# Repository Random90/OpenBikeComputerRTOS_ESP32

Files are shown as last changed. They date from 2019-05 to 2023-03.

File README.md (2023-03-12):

# Open Bike Computer RTOS

## Summary
This repo is an open source bike computer based on freeRTOS on ~~ESP8266~~ ESP32. (ESP32 is much newer hardware, no reason to stick with esp8266 right now)
This is an attempt of learning C and freeRTOS env. I've first made bike computer using arduino nano, so this might be refered as version 2. I've also tackled a little of 3d design in blender to create a case for this bike computer.

Creating community around this project for all programmers riding their bikes would be awesome :)

## Features
### Core:
- current speed, distance, time
- average, max speed, total distance

### Memory:
- average/max speed and total distance are stored on the device (not synchronized for now, only local)

### Display:
- shows main and detailed ride data
- bottom half of the screen changes automaticly (8s 'big' distance, 3s details)

### Synchronization using WiFi:
- synchronize ride data with OBC Server (see https://github.com/Random90/OBC_Server)
- wifi settings are hardcoded at compile-time
- data is sent the the obc_server on ride stop as a new ride after 30 seconds of inactivity (configurable at compile-time)
- ride is restarted automaticly after ride synchonization succeded
- sntp time synchronization - sets timestamp for your rides 
### Current supported hardware:
- ESP32
- Reed Switch
- pcd8544 Nokia 5110 LCD

### 3D Printable case
See /3dcase folder for files. Print both "obc_case_bottom" and obc_case_top" .stl files.

### Additional funcionality TODOS and ideas:
- better sleep mode for battery performance
- local ride storage for later sync (on new ride started by button press) (spiffs)
- full ride logs with file rotation
- wifi access point setup, multiple WIFI access point settings
- timezone settings for time display
- modularization of components (start with screen selection at compile-time)
- different hardware support e.g different type of screens like OLED, E-ink, color LCD
- buttons
- automatic screen brightness
- live, reed impulse online sync (share your ride data realtime)
- sync with Strava API, Wifi geolocation.
- Even later in future: GPS module, GPRS module for live tracking. 

## Hardware

## Prototype version

Pritable case for version with no soldering required, everything connected with Dupont cables. Uses ESP devkit with pins, nokia 5110 screen with pins soldered. Powered up by micro usb cable.

prorotype

### Required components 
- ESP_WROOM_32 DEVKIT V1 
- Nokia 5110 LCD HXE
- Reed switch

### Default wiring
OBC uses VSPI (can be HSPI, but I use it for debug) to connect to LCD:
| ESP32 | LCD |
--- | --- |
| D4 | RST |
| D5 | CE |
| D25 | DC |
| D19 | DIN |
| D18 | CLK |
| 3V3/5V | VIN |
| RX2/G16 | BL |
| GND | GND |

ReedSwitch -> ESP D21 PIN -> GND

JTAG CJMCU-2232HL (note to myself)

| ESP32 | JTAG |
--- | --- |
| D13 | AD0 |
| D12 | AD1 |
| D15 | AD2 |
| D14 | AD3 |
| GND | GND |
## Micro fork version with battery
Work in progress!
## Standard version
Soon
## Standard version with battery
Soon+

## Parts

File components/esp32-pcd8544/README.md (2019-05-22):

# ESP32-PCD8544

A dedicated driver library implementation of PCD8544 graphic controller for
[Espressif IoT Development Framework (ESP-IDF)](https://github.com/espressif/esp-idf).

(PCD8544 is a.k.a. [Nokia 5110 LCD module](https://www.google.co.jp/search?q=nokia5110+lcd&tbm=isch)).

Documentation and API reference is available at readthedocs.org.


http://esp32-pcd8544.readthedocs.io/en/latest/

Application examples are in separeted repository: https://github.com/yanbe/esp32-pcd8544-examples

## Key Features

- All functionalities in the PCD8544 datasheet are implemented
- Enforce native pin assignemnt for fast and low latency IO\_MUX direct IO.
- Manual Pin assignment is availble via API  ( no #define PIN\_NUM\_XX in header files)
- Asyncronous DMA-transfer mode is supported on HSPI / VSPI host
- Efficient draw lines / formatted text / bitmap APIs
- Good sample codes / examples (TBD)

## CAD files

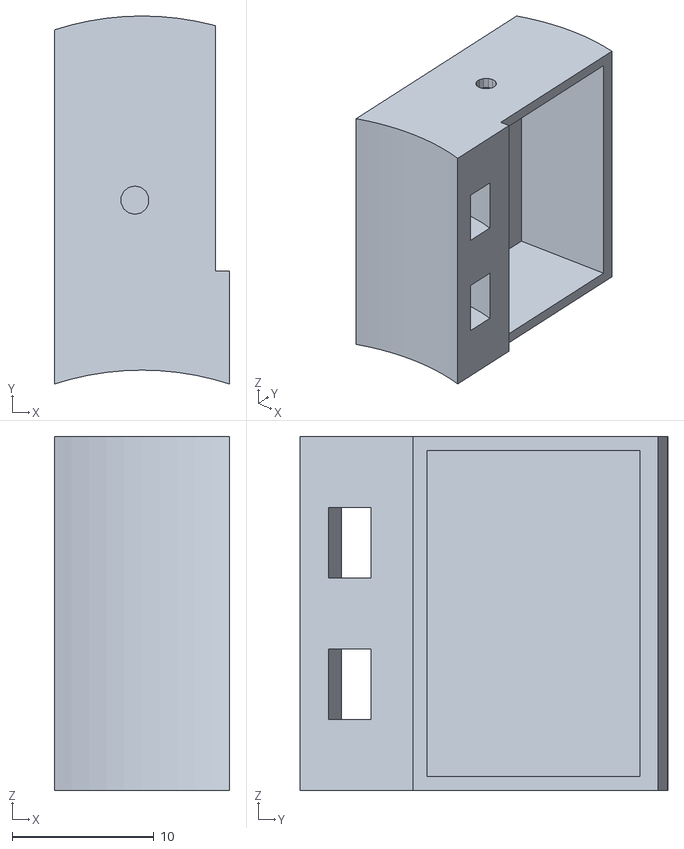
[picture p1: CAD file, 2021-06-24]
3dcase/reedSwitchHolder-main.stl
12.4 x 26.0 x 25.0

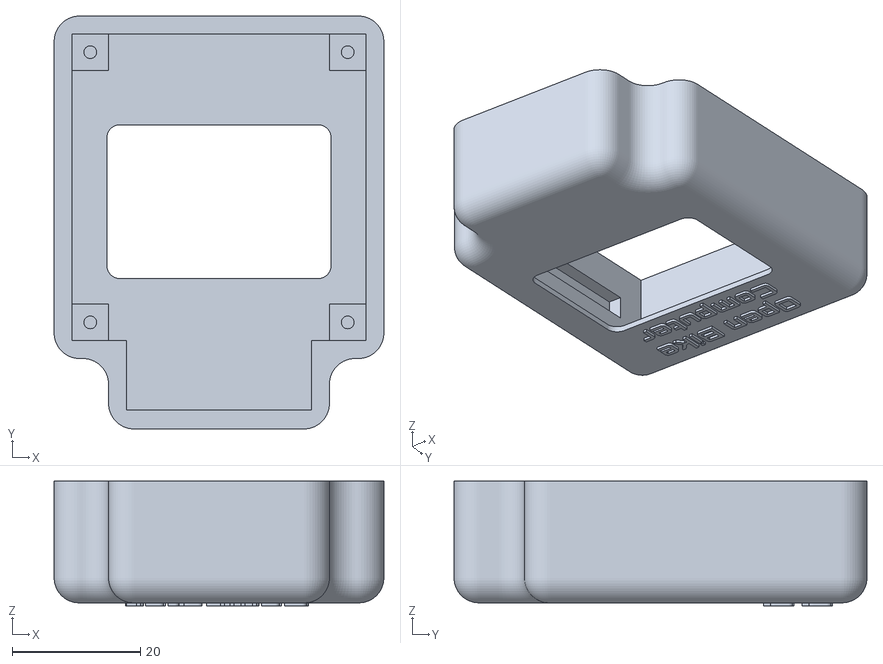
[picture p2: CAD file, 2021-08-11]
3dcase/obc_case_top.stl
51.5 x 64.5 x 19.5

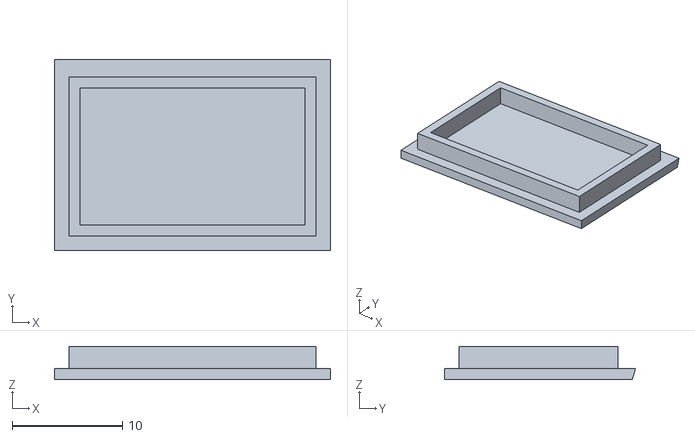
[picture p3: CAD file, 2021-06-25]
3dcase/reedSwitchHolder-cap.stl
25.0 x 17.3 x 3.00

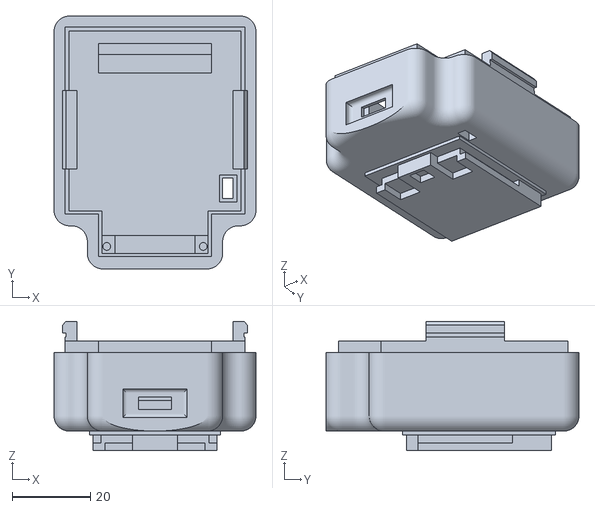
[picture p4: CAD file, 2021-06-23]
3dcase/obc_case_bottom.stl
51.5 x 64.5 x 33.0

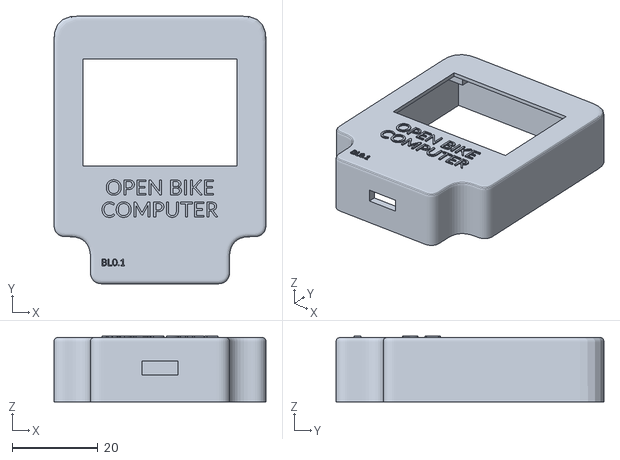
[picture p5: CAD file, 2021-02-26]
3dcase/obc_case_top_text.obj
49.5 x 62.5 x 15.3

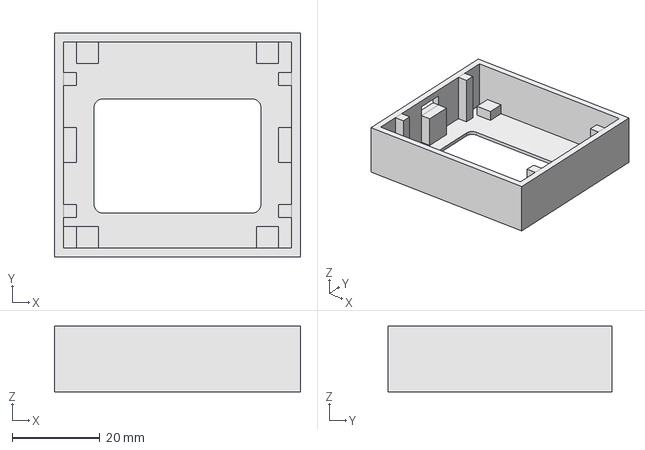
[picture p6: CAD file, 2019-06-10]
3dcase/v1.2_front.FCStd
56.0 x 51.0 x 15.0 mm

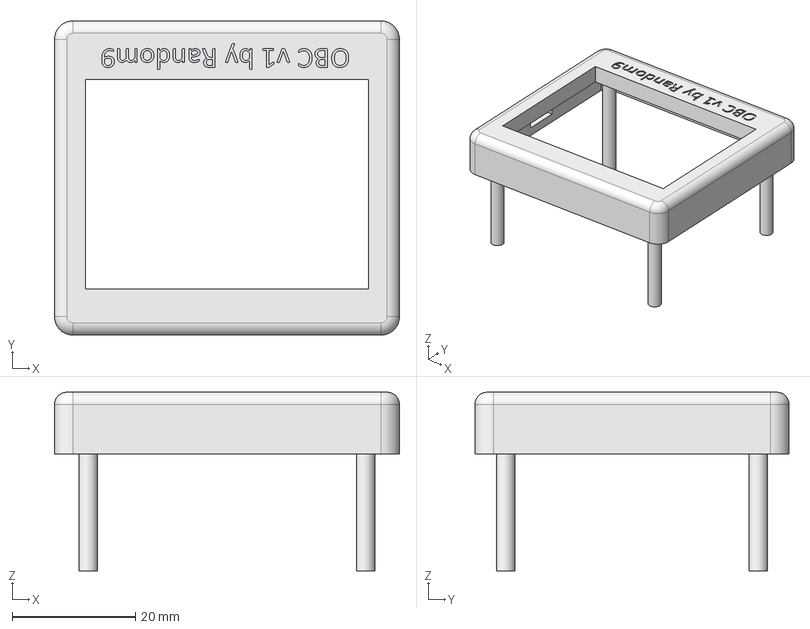
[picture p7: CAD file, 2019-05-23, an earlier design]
3dcase/v1_front.FCStd
56.0 x 51.0 x 29.0 mm

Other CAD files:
3dcase/v1.1_front.FCStd
3dcase/source/obc_case_bottom.blend
3dcase/source/obc_case_bottom_m.blend
3dcase/source/obc_case_mount_only.blend
3dcase/source/obc_case_top.blend
3dcase/source/reedSwitchHolder.blend
3dcase/v1.1_front.obj
3dcase/v1.2_front.obj
3dcase/v1_front.obj

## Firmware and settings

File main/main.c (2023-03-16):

#ifndef NO_SCREEN
#include "Tasks/screen_pcd8544/screen_pcd8544.h"
#include "driver/spi_common.h"
#endif

#include <stdio.h>
#include <stdlib.h>

#include "Tasks/core/calcRideParamsOnISR.task.h"
#include "Tasks/core/rideStatusWatchdog.task.h"
#include "Tasks/storage/spiffs_main.h"
#include "Tasks/sync/obc_rest.task.h"
#include "Tasks/sync/sntp.task.h"
#include "driver/gpio.h"
#include "esp_event_base.h"
#include "esp_log.h"
#include "esp_system.h"
#include "freertos/FreeRTOS.h"
#include "freertos/queue.h"
#include "freertos/task.h"
#include "nvs_flash.h"
#include "obc.h"
#include "sdkconfig.h"
#include "settings.h"
#include "utils/math.h"

#define TAG "OBC_MAIN"

// obc event loop
ESP_EVENT_DEFINE_BASE(OBC_EVENTS);
esp_event_loop_handle_t obc_events_loop;
esp_event_loop_args_t obc_events_loop_args = {
    .queue_size = 5,
    .task_name = "obc_events_loop_task",
    .task_priority = 7,
    .task_stack_size = 2048,
    .task_core_id = tskNO_AFFINITY};

// declare global queues
QueueHandle_t reed_evt_queue = NULL;

// declare OBC global ride params
ride_params_t rideParams = {
    .moving = false,
    .rotations = 0,
    .prevRotationTickCount = 0,
    .totalRideTimeMs = 0,
    .speed = 0.0,
    .avgSpeed = 0.0,
    .distance = 0.0,
    .maxSpeed = 0.0,
    .globalMaxSpeed = 0.0,
    .totalDistance = 0.0,
    .startedTimestamp = 0};

// IRAM_ATTR - function with this will be moved to RAM in order to execute faster than default from flash
static void IRAM_ATTR vReedISR(void* arg) {
    BaseType_t xHigherPriorityTaskWoken = pdFALSE;
    TickType_t xLastReedTickCount = xTaskGetTickCountFromISR();

    xQueueSendFromISR(reed_evt_queue, &xLastReedTickCount, &xHigherPriorityTaskWoken);
    if (xHigherPriorityTaskWoken) {
        portYIELD_FROM_ISR();
    }
}

void vInitTasks() {
    xTaskCreate(&vCalcRideParamsOnISRTask, "vCalcRideParamsOnISRTask", 2048, NULL, 6, NULL);
    xTaskCreate(&vRideStatusWatchdogTask, "vRideStatusIntervalCheckTask", 2048, NULL, 3, NULL);
    xTaskCreate(&vSntpSyncTask, "vSntpSyncTask", 4096, NULL, 3, NULL);
    vRegisterServerSyncTask();
}

void vAttachInterrupts() {
    ESP_LOGI(TAG, "Attaching reed switch interrupt");
    // create queue for the reed interrupt
    reed_evt_queue = xQueueCreate(10, sizeof(uint32_t));

    // configure reed switch gpio
    gpio_config_t io_conf;
    io_conf.mode = GPIO_MODE_INPUT;
    // bit mask of the pins that you want to set,e.g.GPIO18/19
    io_conf.pin_bit_mask = 1ULL << REED_IO_NUM;
    io_conf.pull_up_en = 1;
    io_conf.pull_down_en = 0;
    io_conf.intr_type = GPIO_INTR_NEGEDGE;
    // configure GPIO with the given settings
    gpio_config(&io_conf);
    // gpio_set_intr_type(REED_IO_NUM, GPIO_INTR_NEGEDGE);
    gpio_install_isr_service(ESP_INTR_FLAG_DEFAULT);
    gpio_isr_handler_add(REED_IO_NUM, vReedISR, NULL);
}

void vInitNVS() {
    esp_err_t ret = nvs_flash_init();
    if (ret == ESP_ERR_NVS_NO_FREE_PAGES || ret == ESP_ERR_NVS_NEW_VERSION_FOUND) {
        ESP_ERROR_CHECK(nvs_flash_erase());
        ret = nvs_flash_init();
    }
    ESP_ERROR_CHECK(ret);
}

void testHandler(void* handler_args, esp_event_base_t base, int32_t id, void* event_data) {
    ESP_LOGI(TAG, "handling %s %" PRIu32, base, id);
}

void app_main() {
    ESP_LOGI(TAG, "Initializing");
    ESP_ERROR_CHECK(esp_event_loop_create_default());
    // event loop created with task with priority 7
    ESP_ERROR_CHECK(esp_event_loop_create(&obc_events_loop_args, &obc_events_loop));

    vInitNVS();
    vInitSpiffs();
    vAttachInterrupts();
    vInitTasks();
#ifndef NO_SCREEN
    vInitPcd8544Screen();
#endif

    ESP_ERROR_CHECK(esp_event_handler_register_with(obc_events_loop, OBC_EVENTS, ESP_EVENT_ANY_ID, testHandler, obc_events_loop));
    ESP_LOGI(TAG, "Startup complete");
}

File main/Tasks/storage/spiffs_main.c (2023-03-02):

#include "spiffs_main.h"

#include "esp_err.h"
#include "esp_log.h"
#include "esp_spiffs.h"
#include "obc.h"

#define TAG "SPIFFS_MAIN"

//@TODO saving ride data

TaskHandle_t spiffsSyncOnStopTaskHandle = NULL;

// values read from files
float maxSpeedFileBuff = 0.00;
float totalDistanceFileBuff = 0.00;

void vReadMaxSpeed() {
    FILE *fmaxSpeed = fopen("/spiffs/max_speed", "rb");
    if (fmaxSpeed == NULL) {
        ESP_LOGE(TAG, "Failed to open file max_speed");
        return;
    } else {
        fread(&maxSpeedFileBuff, 1, sizeof(maxSpeedFileBuff), fmaxSpeed);
        fclose(fmaxSpeed);
        ESP_LOGI(TAG, "max speed from file %f", maxSpeedFileBuff);
    }
}

void static vReadTotalDistance() {
    FILE *ftotalDistance = fopen("/spiffs/total_distance", "rb");
    if (ftotalDistance == NULL) {
        ESP_LOGE(TAG, "Failed to open file total_distance");
        return;
    } else {
        fread(&totalDistanceFileBuff, 1, sizeof(totalDistanceFileBuff), ftotalDistance);
        fclose(ftotalDistance);
        ESP_LOGI(TAG, "total distance from file %f", totalDistanceFileBuff);
    }
}

static void vSaveMaxSpeed(float speed) {
    ESP_LOGI(TAG, "[SAVING] maxSpeed: %f", speed);
    FILE *fmaxSpeed = fopen("/spiffs/max_speed", "wb");
    if (fmaxSpeed == NULL) {
        ESP_LOGE(TAG, "Failed to open file max_speed for update");
        return;
    } else {
        fwrite(&speed, 1, sizeof(speed), fmaxSpeed);
        fclose(fmaxSpeed);
        maxSpeedFileBuff = speed;
    }
}

static void vSaveTotalDistance() {
    if (rideParams.totalDistance > totalDistanceFileBuff) {
        ESP_LOGI(TAG, "[SAVING] totalDistance: %f", rideParams.totalDistance);
        FILE *fTotalDistance = fopen("/spiffs/total_distance", "wb");
        if (fTotalDistance == NULL) {
            ESP_LOGE(TAG, "Failed to open file total_distance for update");
            return;
        } else {
            fwrite(&rideParams.totalDistance, 1, sizeof(rideParams.totalDistance), fTotalDistance);
            fclose(fTotalDistance);
            totalDistanceFileBuff = rideParams.totalDistance;
        }
    }
}

static void clearCorruptedData() {
    if (maxSpeedFileBuff > 227.72) {
        ESP_LOGW(TAG, "MaxSpeed corrupted, overwriting");
        maxSpeedFileBuff = 0;
        vSaveMaxSpeed(maxSpeedFileBuff);
    }
}

static void vRideStopEventHandler() {
    xTaskNotifyGive(spiffsSyncOnStopTaskHandle);
}

// update rideParams with max speed, total distance from files before ride
static void vPopulateRideParamsFromStorage() {
    // @TODO mutex?
    vReadMaxSpeed();
    vReadTotalDistance();
    clearCorruptedData();

    rideParams.globalMaxSpeed = maxSpeedFileBuff;
    rideParams.totalDistance = totalDistanceFileBuff;
}

void vInitSpiffs() {
    ESP_LOGI(TAG, "Initializing SPIFFS");

    esp_vfs_spiffs_conf_t conf = {
        .base_path = "/spiffs",
        .partition_label = NULL,
        .max_files = MAX_FILES,
        .format_if_mount_failed = true};

    esp_err_t ret = esp_vfs_spiffs_register(&conf);

    if (ret != ESP_OK) {
        ESP_LOGE(TAG, "Failed to initialize SPIFFS (%s)", esp_err_to_name(ret));
        return;
    }

    size_t total = 0, used = 0;
    ret = esp_spiffs_info(conf.partition_label, &total, &used);
    if (ret != ESP_OK) {
        ESP_LOGE(TAG, "Failed to get SPIFFS partition information (%s)", esp_err_to_name(ret));
    } else {
        ESP_LOGI(TAG, "Partition size: total: %d, used: %d", total, used);
    }

    vPopulateRideParamsFromStorage();
    ESP_ERROR_CHECK(esp_event_handler_register_with(obc_events_loop, OBC_EVENTS, RIDE_STOP_EVENT, vRideStopEventHandler, NULL));
    xTaskCreate(&vSpiffsSyncOnStopTask, "vSpiffsSyncOnStopTask", 2048, NULL, 3, &spiffsSyncOnStopTaskHandle);
}

void vSpiffsSyncOnStopTask(void *data) {
    while (true) {
        ulTaskNotifyTake(pdTRUE, SPIFFS_SYNC_INTERVAL_MS / portTICK_PERIOD_MS);
        if (rideParams.maxSpeed > maxSpeedFileBuff) {
            vSaveMaxSpeed(rideParams.maxSpeed);
            rideParams.globalMaxSpeed = maxSpeedFileBuff;
        }
        vSaveTotalDistance();
    }
}

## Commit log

2018-12-15 Double LED blinking, second task
    Just testing possibilities
2018-12-17 Status flags passing fixed
    you cant pass by reference bool as void*, even as you cast it. This status variables can be just globals.
    Using task param is rather designated for dynamic task creation - static values can be just used as other globals
    [main.c]
2018-12-17 another redundant task param fix
    [main.c]
2018-12-18 GPIO interrupt for reed switch
    counting switches and last switch time.
    Use 1 uF capacitor to prevent double falling edges on circuit closing.
    Removed fake reed switch functions :)
    @TODO use queue to calculate basic ride values like speed
    [main.c]
2018-12-19 crude arduino code for simulating bike with reed switch installed
    i suppose this is enough for now
2018-12-22 self test as one task, task stack size optim, mock reed slow switch fix
    self test as one task, task stack size optim, mock reed slow switch fix
    [main.c, main.cpp]
2019-05-15 blink using vdelayUntil, isr test
    isr not working still :P
    [main.c]
2019-05-21 working interrupt from mock switch
2019-05-22 use queue for reed interrupt
2019-05-23 3d model of front part of the v1 case
    for test print
    [v1_front.FCStd, v1_front.obj]
2019-05-23 v1 is broken, v1.1 is on the way
    [v1.1_front.FCStd, v1_front.FCStd]
2019-05-24 v1.1 was almost good
    v1.2 fixes some sketches
    TODO ESPHolderPart needs to be redrawn with 2mm move
    TODO usb pocket to redo
    TODO lcd opening could be smaller
    TODO add some curves!
    [v1.1_front.FCStd, v1.1_front.obj, v1.2_front.FCStd]
2019-06-10 v1.2 of front. fixed pcb holders
    btw, freeCAD is garbage. It destroys sketches at random!
    [v1.2_front.FCStd, v1.2_front.obj]
2020-03-14 Moved logs to ESP_LOGI from printf
2020-03-15 added screen powersave features - screen stops refreshing when not moving - screen turns off after POWER_SAVE_DELAY timeout
2020-05-02 main pcd screen styling + poc average bar - added units - added middle line - added vertical line for speed current/average ratio
2020-05-10 fixed big diffMS after sleep - fixed bad averages and times after waking up from deep sleep by skipping first interrupt
    [main.c]
2020-05-11 spiffs working init test
    [partition_table.csv]
2020-05-23 write/read maxSpeed from binary file - max speed read on init - max speed update on ride stop - added fix for infinity speed in one case - minor code cleans
    [main.c, spiffs_main.c]
2021-01-13 spiffs maxSpeed and totalDistance comparison fix - minor code refactor
    [main.c, spiffs_main.c]
2021-02-26 new 3d print case, mounting bottom test and top
    [case2.blend, obc_case_mount_crude.blend, obc_case_mount_crude2.blend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]
2021-02-28 3d case top part updates
    [obc_case_top.blend, obc_case_top_print.blend, obc_case_top_print_txt.blend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]
2021-03-11 3d case files cleanup, cleaned top mesh
    [case2.blend, obc_case_bottom.blend, obc_case_mount_crude.blend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]
2021-03-11 bevel modifiers for top of the case removed window in bottom part - wip
    [obc_case_bottom.blend]
2021-03-16 3d case bottom part usb outer hole added, bevel fixes
    [obc_case_bottom.blend]
2021-04-14 bottom case with mouting element merged + glue edges
    [obc_case_bottom.blend, obc_case_bottom.stl, obc_case_bottom_m.blend]
2021-04-29 changed screen spi to vspi, enabled jtag debugging - moved reed switch gpio
2021-06-20 readme update. features, todos, wiring setup
2021-06-21 case updates v1, exports
    [obc_case_bottom.blend, obc_case_bottom.stl, obc_case_top.blend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]
2021-06-21 3c case files cleanup
    [case2.blend, obc_case_bottom.blend, obc_case_bottom.stl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]
2021-06-21 fixed font on top case
    [obc_case_top.blend, obc_case_top.stl]
2021-06-21 3dcase: fix screen window positioning, bevel
    [obc_case_top.blend]
2021-06-21 3dcase: top 4mm longer for screen window protector
    [obc_case_top.blend, obc_case_top.stl]
2021-06-22 3dcase: top part fixes - thicker walls, - snapping row 4mm - higher screen corner base by 2mm to include screen protector
    [obc_case_top.blend, obc_case_top.stl]
2021-06-22 3dcase: bottom thicker walls, higher protrusion
    [obc_case_bottom.blend]
2021-06-22 3dcase: botton esp fit fixed
    [obc_case_bottom.blend]
2021-06-22 3dcase: cantilever joints, bot walls fixes
    [obc_case_bottom.blend, obc_case_bottom.stl, obc_case_top.blend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]
2021-06-23 3dcase: bottom reed hole fixes, valid stl export
    [obc_case_bottom.blend, obc_case_bottom.stl]
2021-06-24 3dcase: v1 final - top fixes, thinner walls, lowered screen stands
    [obc_case_top.blend, obc_case_top.stl]
2021-06-24 3dcase: reed switch case v1
    [reedSwitchHolder-cap.stl, reedSwitchHolder-main.stl, reedSwitchHolder.blend]
2021-06-25 3dcase: added tolerances to reed switch cap
    [reedSwitchHolder-cap.stl, reedSwitchHolder.blend]
2021-06-30 test fix of high speed readings
    [main.c]
2021-08-11 3dcase: cantiveler joins fixed for extended use - better grip to resist bumps on terrain roads
    [obc_case_bottom.blend, obc_case_bottom.stl, obc_case_top.blend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]
2021-08-11 3dcase: applied modifiers for stl export
    [obc_case_top.stl]
2021-08-31 Revert "3dcase: cantiveler joins fixed for extended use"
    This reverts commit 0afda31f89df9e80e6ab396e467d33b55b84647c.
    [obc_case_bottom.blend, obc_case_bottom.stl, obc_case_top.blend]
2021-08-31 updated pinout in readme for different esp32 dev kit
2021-09-16 Screen refresher task major refactor - handled by obc event loop using dynamic task - renderer runs in not moving state while screen is on - much cleaner solution, prepared for better screen switchin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
2021-09-18 timebased screen switcher instad of frame based - different screen delays
2021-09-18 screens rework, clock with CEST timezone hardcoded - ride details are shown below current speed, which stays on top all the time now - bottom half of the screen alternates between distance and details
2021-09-22 simple, soft filtering of noise (from cables?)
2021-09-22 fix global max speed not displaying on stop
    [spiffs_main.c]
2021-10-06 fixed reed noise filtering - prevent calculating
2023-02-27 lock the old esp framework (3.5) - shall I go back to developing new features? :)
2023-03-12 esp32-c3 beetle env config. conditional pcd compilation removed blinker test code
2023-03-12 switched reed input to pullup resistor for high frequency noise resistance - fixed build flag
    [main.c]
2023-03-16 better ISR handling, improved bouncing/noise filter
    [main.c]
2024-05-30 possibly fixed crashing on wheel rotation after longer break
2025-09-15 Update README to reflect ESP32 and project status
    Not planning to make more versions anymore. Using open source openTracks app with BLE sensors is much better solution to bicycle computer problem.
2026-04-06 Update README with additional prototype image
    Added an additional image to the prototype section of the README.
